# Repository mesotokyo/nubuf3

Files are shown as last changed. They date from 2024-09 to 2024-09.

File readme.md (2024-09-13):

# MST DRIVE (Nutube Powered Booster/Overdrive) schematic and PCB for KiCAD

(Japanese version is [here](readme_ja.md) / 日本語版は[こちら](readme_ja.md))

## What is this?

KiCAD files to build PCB of the MST DRIVE (Nutube Powered Booster/Overdive). These files are created with KiCad 6.0.

For more information about MST DRIVE, please check https://meso.tokyo/works/drive .

## Notice

 * This schematic and PCB file need a `ak_misc` footprint library in [mst-kicad-lib](https://github.com/mesotokyo/mst-kicad-lib). 
 * It is assumed that this schematic will be used with [voltboost2e](https://github.com/mesotokyo/voltboost2e) DC-DC converter unit.

## DISCLAIMER

FILES IN THIS REPOSITORY ARE PROVIDED "AS IS", WITHOUT WARRANTY OF ANY KIND, EXPRESS OR IMPLIED, INCLUDING BUT NOT LIMITED TO THE WARRANTIES OF MERCHANTABILITY, FITNESS FOR A PARTICULAR PURPOSE AND NONINFRINGEMENT. IN NO EVENT SHALL THE AUTHORS OR COPYRIGHT HOLDERS BE LIABLE FOR ANY CLAIM, DAMAGES OR OTHER LIABILITY, WHETHER IN AN ACTION OF CONTRACT, TORT OR OTHERWISE, ARISING FROM, OUT OF OR IN CONNECTION WITH IN FILES IN THIS REPOSITORY OR THE USE OR OTHER DEALINGS IN FILES IN THIS REPOSITORY.

## License

CC BY 4.0. For more information, please check https://creativecommons.org/licenses/by/4.0/ .

## Author

MST/mesotokyo

 - https://meso.tokyo/
 - https://x.com/mesotokyox

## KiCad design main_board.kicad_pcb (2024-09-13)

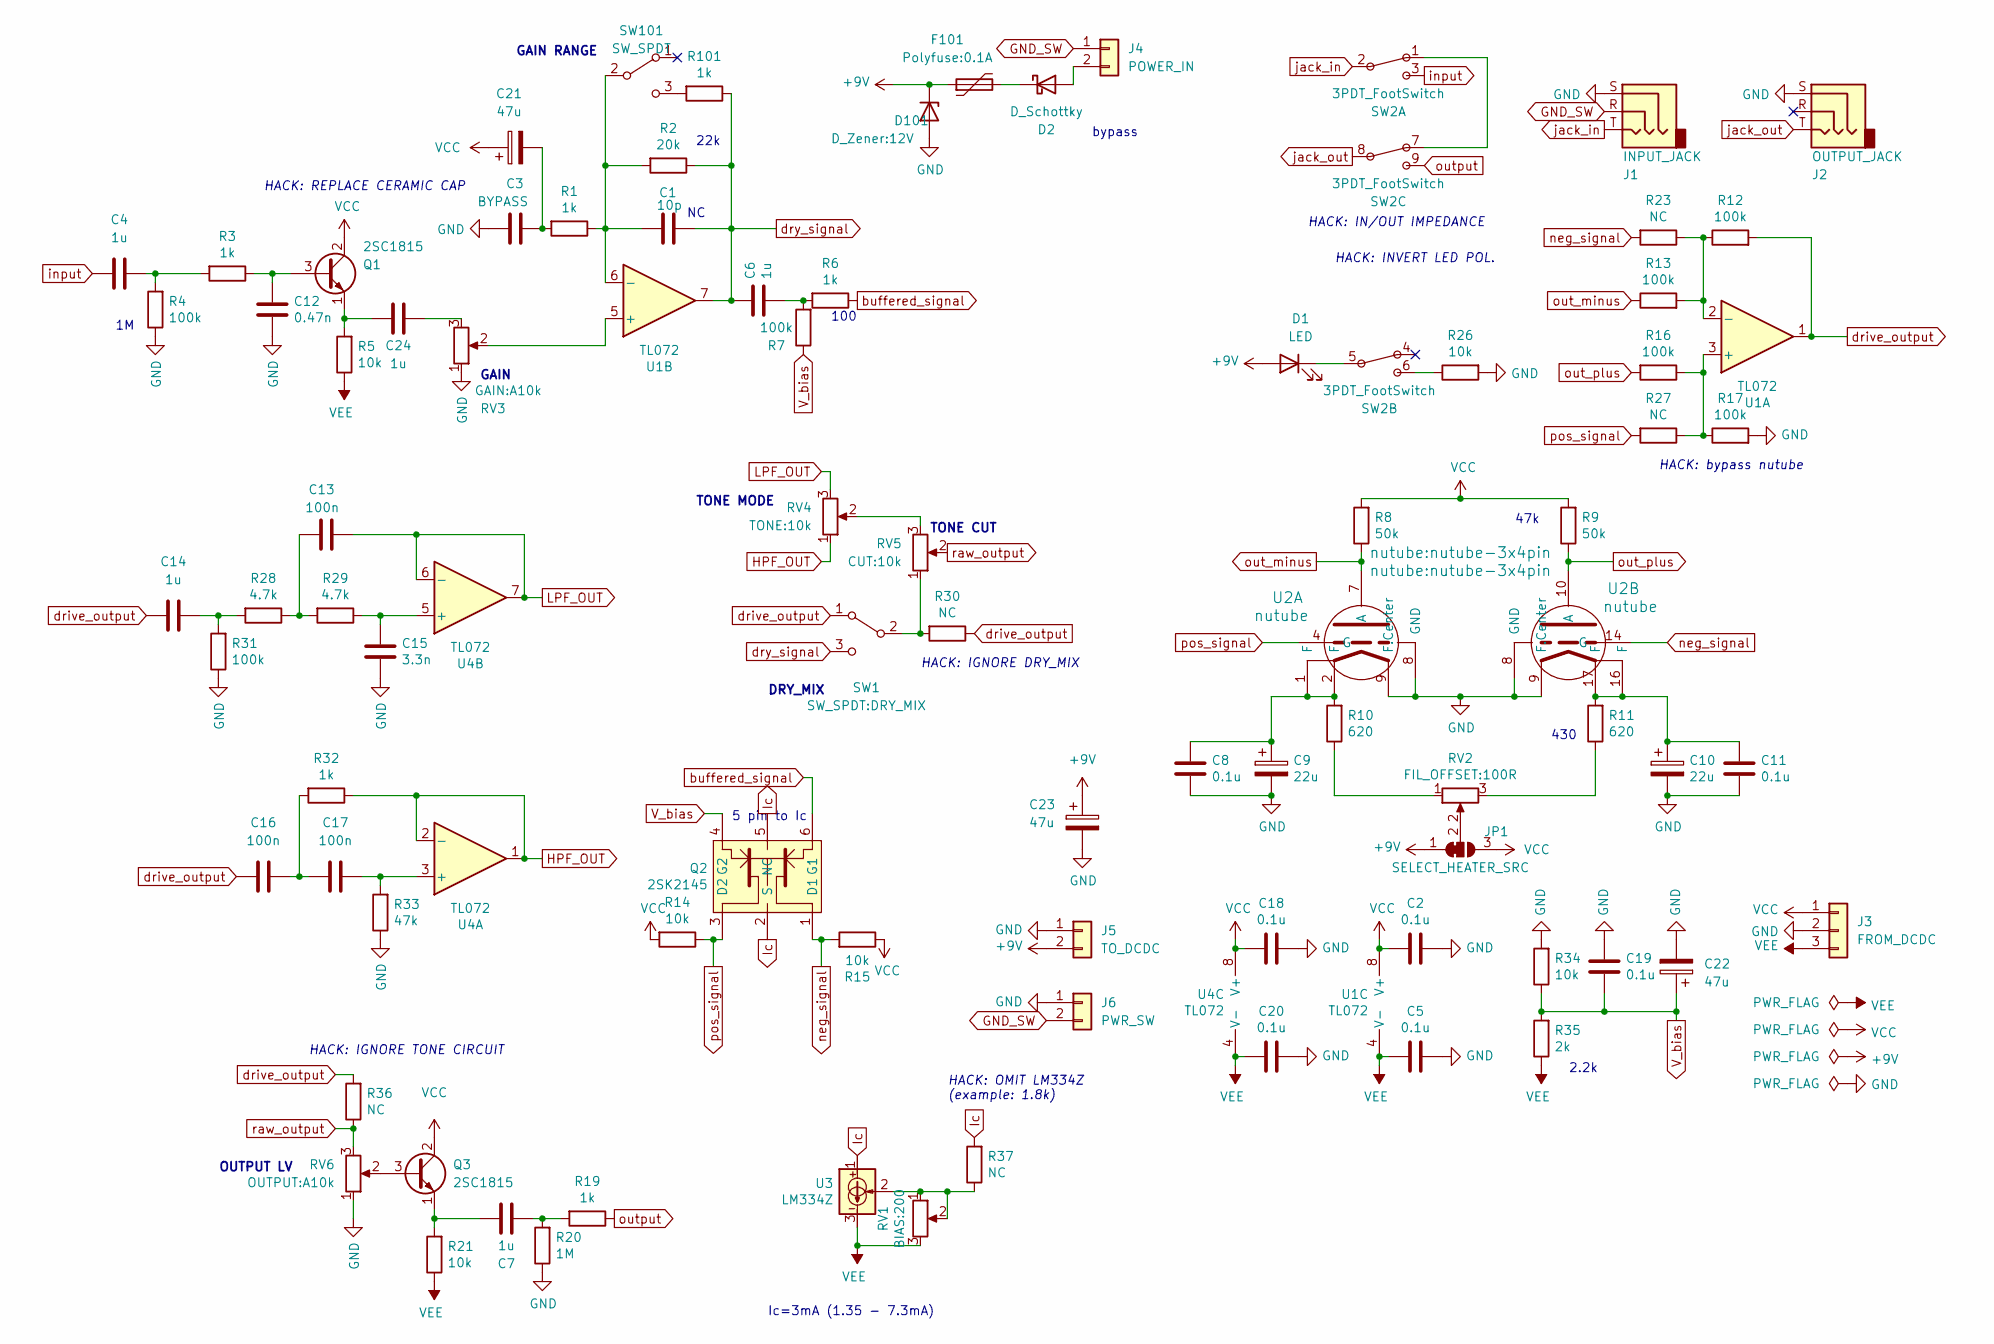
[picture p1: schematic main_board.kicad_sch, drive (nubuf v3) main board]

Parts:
C1: 10p; C_Disc_D3.0mm_W1.6mm_P2.50mm
C2, C5, C8, C11, C18, C19, C20: 0.1u; C_Disc_D3.0mm_W1.6mm_P2.50mm
C3: BYPASS; C_Disc_D10.5mm_W5.0mm_P5.00mm
C4, C6, C7, C14, C24: 1u; C_Rect_L7.2mm_W7.2mm_P5.00mm_with_SMD_3216
C9, C10: 22u; CP_Radial_D6.3mm_P2.50mm
C12: 0.47n; C_Rect_F2D_L6.0mm_W3.0mm_P3.50mm
C13, C16, C17: 100n; C_Rect_L7.0mm_W2.5mm_P5.00mm
C15: 3.3n; C_Rect_F2D_L6.0mm_W3.0mm_P3.50mm
C21: 47u; CP_EIA-7343-15_Kemet-W_Pad2.25x2.55mm_HandSolder
C22, C23: 47u; CP_Radial_D8.0mm_P3.50mm
D1: LED; LED_D3.0mm
D2: D_Schottky; D_DO-41_SOD81_P10.16mm_Horizontal
D101: D_Zener:12V; D_DO-41_SOD81_P7.62mm_Horizontal
F101: Polyfuse:0.1A; C_Disc_D4.3mm_W1.9mm_P5.00mm
J1: INPUT_JACK; MJ-187
J2: OUTPUT_JACK; MJ-187
J3: FROM_DCDC; JST_XH_B3B-XH-A_1x03_P2.50mm_Vertical
J4: POWER_IN; JST_XH_B2B-XH-A_1x02_P2.50mm_Vertical
J5: TO_DCDC; JST_XH_B2B-XH-A_1x02_P2.50mm_Vertical
J6: PWR_SW; PinHeader_1x02_P2.54mm_Vertical
JP1: SELECT_HEATER_SRC; SolderJumper-3_P1.3mm_Bridged12_RoundedPad1.0x1.5mm
Q1, Q3: 2SC1815; TO-92_Inline_Wide
Q2: 2SK2145; DIP-6_W7.62mm
R1, R3, R6, R19, R32, R101: 1k; R_Axial_DIN0207_L6.3mm_D2.5mm_P7.62mm_with_SMD
R2: 20k; R_Axial_DIN0207_L6.3mm_D2.5mm_P7.62mm_with_SMD
R4, R7, R12, R13, R16, R17, R31: 100k; R_Axial_DIN0207_L6.3mm_D2.5mm_P7.62mm_with_SMD
R5, R14, R15, R21, R26, R34: 10k; R_Axial_DIN0207_L6.3mm_D2.5mm_P7.62mm_with_SMD
R8, R9: 50k; R_Axial_DIN0207_L6.3mm_D2.5mm_P7.62mm_with_SMD
R10, R11: 620; R_Axial_DIN0207_L6.3mm_D2.5mm_P7.62mm_with_SMD
R20: 1M; R_Axial_DIN0207_L6.3mm_D2.5mm_P7.62mm_with_SMD
R23, R27, R30, R36, R37: NC; R_Axial_DIN0207_L6.3mm_D2.5mm_P7.62mm_with_SMD
R28, R29: 4.7k; R_Axial_DIN0207_L6.3mm_D2.5mm_P7.62mm_with_SMD
R33: 47k; R_Axial_DIN0207_L6.3mm_D2.5mm_P7.62mm_with_SMD
R35: 2k; R_Axial_DIN0207_L6.3mm_D2.5mm_P7.62mm_with_SMD
RV1: BIAS:200; GF063
RV2: FIL_OFFSET:100R; GF063
RV3: GAIN:A10k; POT-16mm
RV4: TONE:10k; POT-16mm
RV5: CUT:10k; POT-16mm
RV6: OUTPUT:A10k; POT-16mm
SW1: SW_SPDT:DRY_MIX; spdt-sw-micro
SW2: 3PDT_FootSwitch
SW101: SW_SPDT; spdt-sw-micro
U1, U4: TL072; DIP-8_W7.62mm
U2: nutube; nutube-3x4pin
U3: LM334Z; TO-92L_Inline_Wide

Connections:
+9V: C23.1, D1.2 (A), D101.1 (K), F101.1, J5.2, JP1.1 (A)
GND: C2.1, C3.1, C5.1, C8.2, C9.2, C10.2, C11.2, C12.2, C15.2, C18.1, C19.1, C20.1, C22.2, C23.2, D101.2 (A), J1.S, J2.S, J3.2, J5.1, J6.1, R4.1, R17.2, R20.1, R26.2, R31.1, R33.1, R34.2, RV3.1, RV6.1, U2.8 (GND), U2.9 (F.Center)
GND_SW: J1.R, J4.1, J6.2
HPF_OUT: R32.1, RV4.1, U4.1, U4.2 (-)
Ic: Q2.2 (S), Q2.5 (NC), R37.2, U3.1
LPF_OUT: C13.2, RV4.3, U4.6 (-), U4.7
unnamed: C1.1, R1.1, R2.2, SW101.2 (B), U1.6 (-)
unnamed: C4.2, R3.2, R4.2
unnamed: C6.2, R6.2, R7.2
unnamed: C7.1, Q3.1 (E), R21.2
unnamed: C7.2, R19.2, R20.2
unnamed: C8.1, C9.1, R10.2, U2.1 (F), U2.2 (F)
unnamed: C10.1, C11.1, R11.2, U2.16 (F), U2.17 (F)
unnamed: C12.1, Q1.3 (B), R3.1
unnamed: C13.1, R28.1, R29.2
unnamed: C14.2, R28.2, R31.2
unnamed: C15.1, R29.1, U4.5 (+)
unnamed: C16.2, C17.1, R32.2
unnamed: C17.2, R33.2, U4.3 (+)
unnamed: C3.2, C21.2, R1.2
unnamed: C24.1, Q1.1 (E), R5.2
unnamed: C24.2, RV3.3
unnamed: D1.1 (K), SW2.5
unnamed: D2.1 (K), F101.2
unnamed: D2.2 (A), J4.2
unnamed: JP1.2 (C), RV2.2
unnamed: Q3.3 (B), RV6.2
unnamed: R10.1, RV2.1
unnamed: R11.1, RV2.3
unnamed: R12.1, R13.2, R23.1, U1.2 (-)
unnamed: R16.1, R17.1, R27.1, U1.3 (+)
unnamed: R26.1, SW2.6
unnamed: R30.2, RV5.1, SW1.2 (B)
unnamed: R37.1, RV1.1, RV1.2, U3.2
unnamed: R101.2, SW101.3 (C)
unnamed: RV3.2, U1.5 (+)
unnamed: RV4.2, RV5.3
unnamed: SW2.1, SW2.7
VCC: C2.2, C18.2, C21.1, J3.1, JP1.3 (B), Q1.2 (C), Q3.2 (C), R8.2, R9.2, R14.2, R15.1, U1.8 (V+), U4.8 (V+)
VEE: C5.2, C20.2, J3.3, R5.1, R21.1, R35.1, RV1.3, U1.4 (V-), U3.3, U4.4 (V-)
V_bias: C19.2, C22.1, Q2.4 (G2), R7.1, R34.1, R35.2
buffered_signal: Q2.6 (G1), R6.1
drive_output: C14.1, C16.1, R12.2, R30.1, R36.2, SW1.1 (A), U1.1
dry_signal: C1.2, C6.1, R2.1, R101.1, SW1.3 (C), U1.7
input: C4.1, SW2.3
jack_in: J1.T, SW2.2
jack_out: J2.T, SW2.8
neg_signal: Q2.1 (D1), R15.2, R23.2, U2.14 (G)
out_minus: R8.1, R13.1, U2.7 (A)
out_plus: R9.1, R16.2, U2.10 (A)
output: R19.1, SW2.9
pos_signal: Q2.3 (D2), R14.1, R27.2, U2.4 (G)
raw_output: R36.1, RV5.2, RV6.3

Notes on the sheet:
GAIN RANGE
GAIN
HACK: REPLACE CERAMIC CAP
HACK: OMIT LM334Z (example: 1.8k)
TONE MODE
HACK: bypass nutube
DRY_MIX
5 pin to Ic
TONE CUT
HACK: INVERT LED POL.
bypass
Ic=3mA (1.35 - 7.3mA)
47k
100
HACK: IN/OUT IMPEDANCE
430
HACK: IGNORE TONE CIRCUIT
OUTPUT LV
22k
2.2k
HACK: IGNORE DRY_MIX

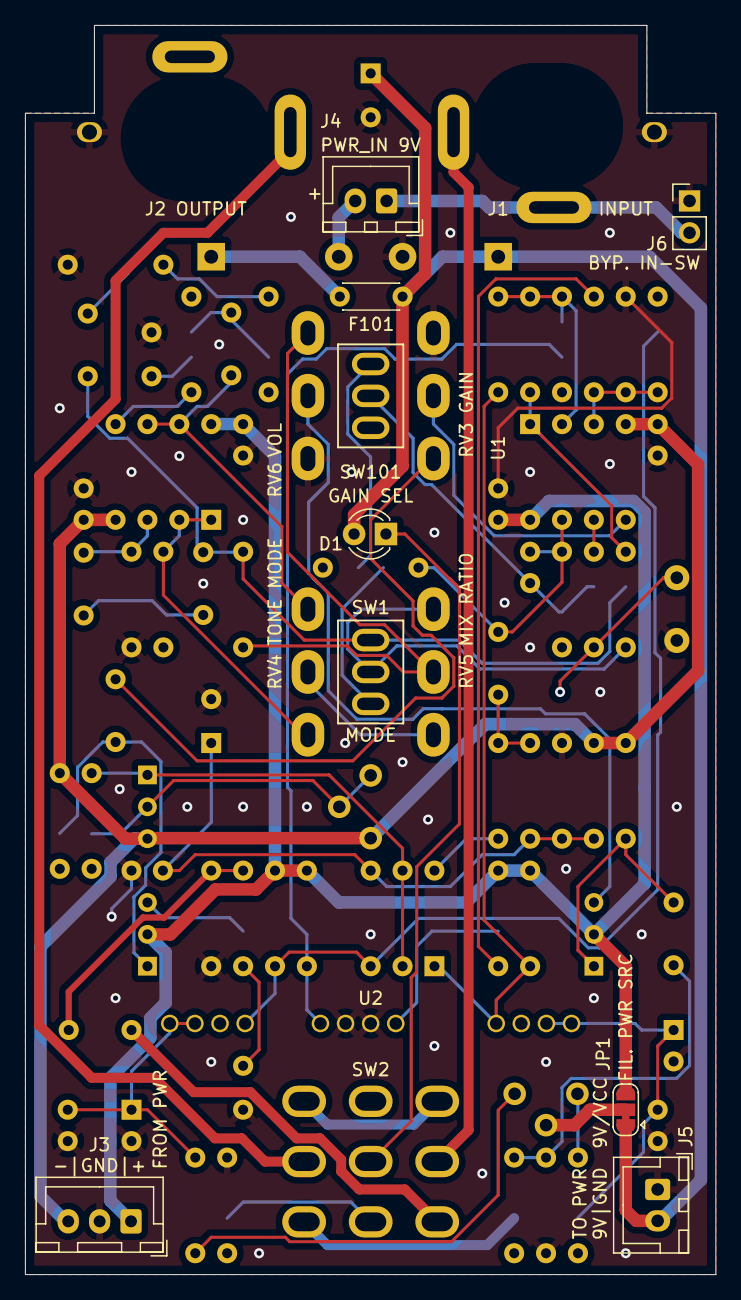
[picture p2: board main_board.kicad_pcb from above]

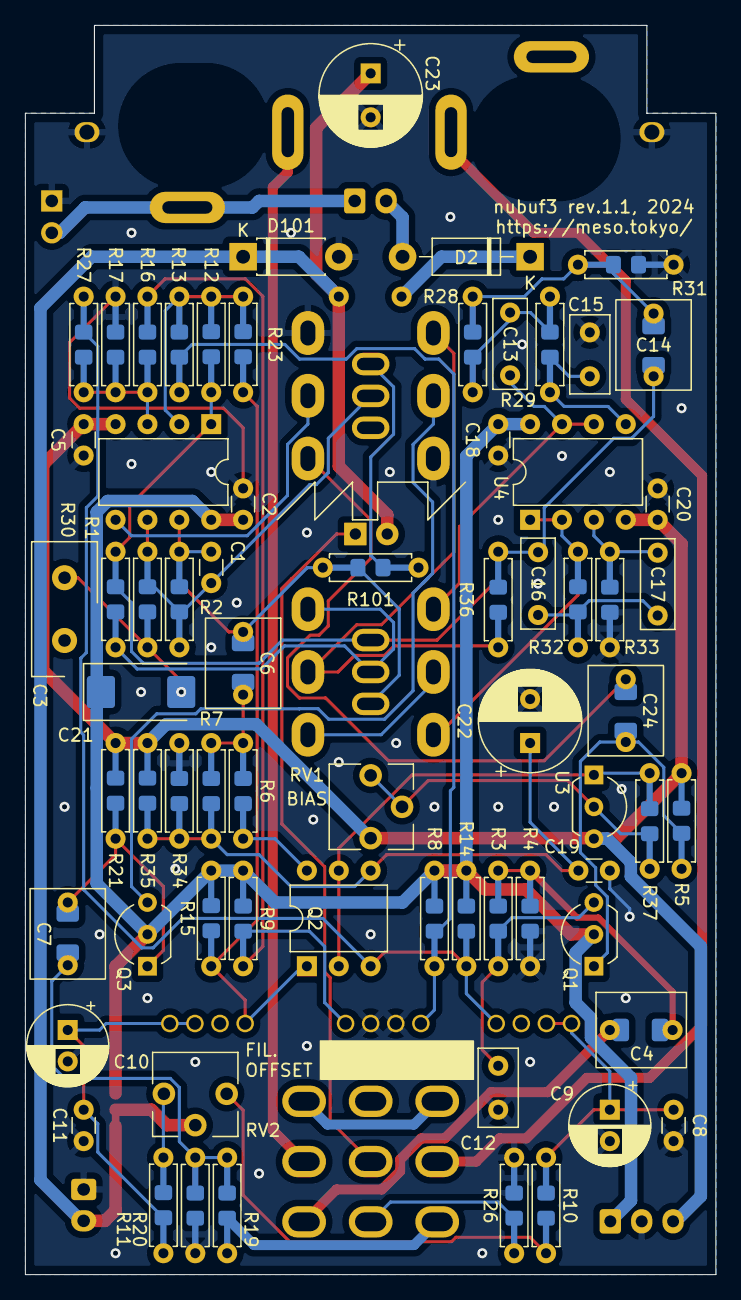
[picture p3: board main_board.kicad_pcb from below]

Board: 2 copper layers, 55.0 x 99.5 mm, 85 parts (68 on the bottom side), 53 nets.

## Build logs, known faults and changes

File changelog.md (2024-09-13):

# Changelog

## v1.0.0 - 2024-08-20

This is first internal version.
